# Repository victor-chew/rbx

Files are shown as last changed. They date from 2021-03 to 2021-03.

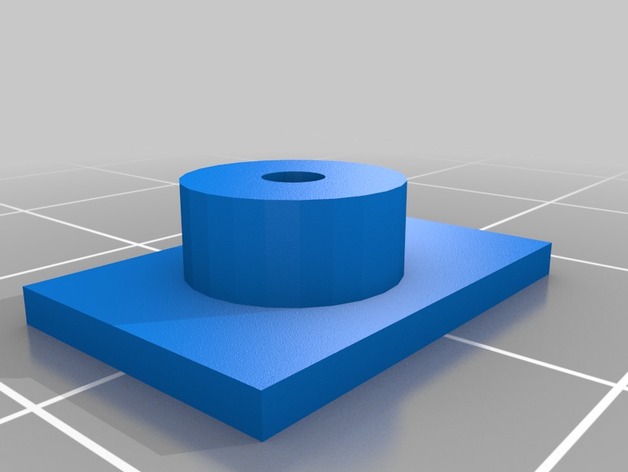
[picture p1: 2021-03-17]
freecad/servo/Printed_SG90_Servo_Connector/images/6eeb7df884c5a71ec6c0490531ae86ac_preview_featured.jpg

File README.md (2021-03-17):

# RBX

### What is RBX?

[RBX](https://rbx.randseq.org/) (*Robotics Brick Extension*) is a robotics kit designed for young tinkerers. It consists of a set of Lego-compatible "bricks" made with common  [Arduino](https://www.arduino.cc/)  components, such as LED, pushbutton, servo, motor etc. The brick housing are printed using a 3D printer. The RBX bricks are hooked up to a microcontroller via standardized "ports". Programming is done via a variant of [Javascript](https://duktape.org) on a browser-based IDE.

rbx mcu assembled Microcontroller (https://rbx.randseq.org/images/rbx/rbx-mcu-assembled.jpg) rbx battery aa Battery (4 x AA) (https://rbx.randseq.org/images/rbx/bricks/rbx-battery-aa.jpg) rbx battery 18650 Battery (18650) (https://rbx.randseq.org/images/rbx/bricks/rbx-battery-18650.jpg) rbx motor power Motor Power) (https://rbx.randseq.org/images/rbx/bricks/rbx-motor-power.jpg) rbx led LED (https://rbx.randseq.org/images/rbx/bricks/rbx-led.jpg) rbx pushbutton Pushbutton (https://rbx.randseq.org/images/rbx/bricks/rbx-pushbutton.jpg) rbx buzzer Buzzer (https://rbx.randseq.org/images/rbx/bricks/rbx-buzzer.jpg) rbx photoresistor Photoresistor (https://rbx.randseq.org/images/rbx/bricks/rbx-photoresistor.jpg) rbx oled OLED Display (https://rbx.randseq.org/images/rbx/bricks/rbx-oled.jpg) rbx rotary switch Rotary Switch (https://rbx.randseq.org/images/rbx/bricks/rbx-rotary-switch.jpg) rbx servo Servo (https://rbx.randseq.org/images/rbx/bricks/rbx-servo.jpg) rbx motor Motor (https://rbx.randseq.org/images/rbx/bricks/rbx-motor.jpg) rbx sonar Sonar (https://rbx.randseq.org/images/rbx/bricks/rbx-sonar.jpg) rbx color sensor Color Sensor (https://rbx.randseq.org/images/rbx/bricks/rbx-color-sensor.jpg)

### Target audience

The target audience is 8-12 year old children who need something between the simplicity of block-based programming environment such as Lego Mindstorm, and a full-blown IDE such as  [Arduino](https://www.arduino.cc/)  or  [PlatformIO](https://platformio.org/). Not only is Javascript the de-facto scripting language, it also eliminates the long compile-build-run cycle, which is more suited for experimentation with impatient young minds.

### Making hardware accessible

One of the first obstacles for a young student trying to break into microcontroller programming is hooking up the desired circuitry on a breadboard. Anything beyond the the introductory "Hello World" LED example requires a ton of wiring, which is quite a lot to ask for a young child. When servos or motors are involved, a separate power rail is required, which makes things even more complicated.

RBX uses various JST connectors to connect to the microcontroller. These are called "ports", which maps to the microcontroller pins. The ports come in 2, 3 and 4-pin variety, and each port has a unique identifier, Other connectors are used for providing power to motors or servos. In this way, hooking up stuff becomes a plug-and-play affair. Since the connectors need to be matching and oriented correctly, this makes it less likely for modules to be hooked up the wrong way.

### Microntroller

For the microcontroller, the ESP32 is chosen. It is incredibly powerful, and comes with built-in WIFI and bluetooth. The development board is also very affordable, available for only a few dollars online. It has a 2-core processor, and has enough RAM and flash storage to run a Javascript interpreter. It also has many pins available, which lets the microcontroller connect to many components simultaneously.

esp32 wroom 32d (https://rbx.randseq.org/images/rbx/esp32-wroom-32d.jpg)

### Programming made easy

For the JavaScript interpreter,  [Duktape](https://duktape.org/)  was ported to the ESP32.  [Duktape](https://duktape.org/)  has very low resource and memory requirement, which makes it particularly suited for a microcontroller.

A browser-based IDE is served directly from the microcontroller, using  [Ace](https://ace.c9.io/)  as the code editor. Once the microcontroller is powered on, the user is able to connect via a web browser and start running JavaScript code immediately. Code can be saved to the flash storage on the ESP32 and retrieved later.

rbx startup 06 (https://rbx.randseq.org/images/rbx/rbx-startup-06.png)

### Conclusion

In summary, RBX is relatively cheap to make, yet it is far more versatile than most of the pre-built electronic/robotic kits on the market. A young maker can get up to speed with the kit very quickly. As more experience is accumulated, he/she can delve into each of the "bricks" to see what makes them tick, or even make them from scratch.

On the software side, although we start with JavaScript, it is quite easy to switch to  [Arduino](https://www.arduino.cc/)  for more complex projects. At the root of RBX is an  [Arduino](https://www.arduino.cc/)  library, which is pretty straightforward to engage with directly for a more experienced  [Arduino](https://www.arduino.cc/)  programmer.

### Resources

 - [RBX website](https://rbx.randseq.org/)
 - [Sample projects](https://rbx.randseq.org/index.php/blinking-led)

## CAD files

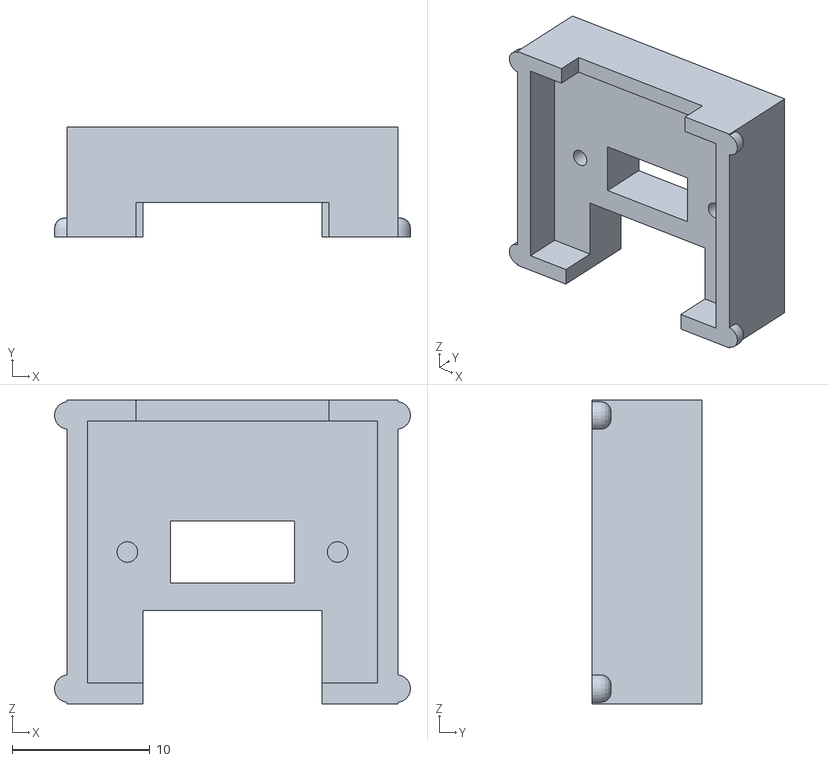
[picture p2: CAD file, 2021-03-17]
freecad/battery-18650/switch.stl
25.8 x 8.00 x 22.0

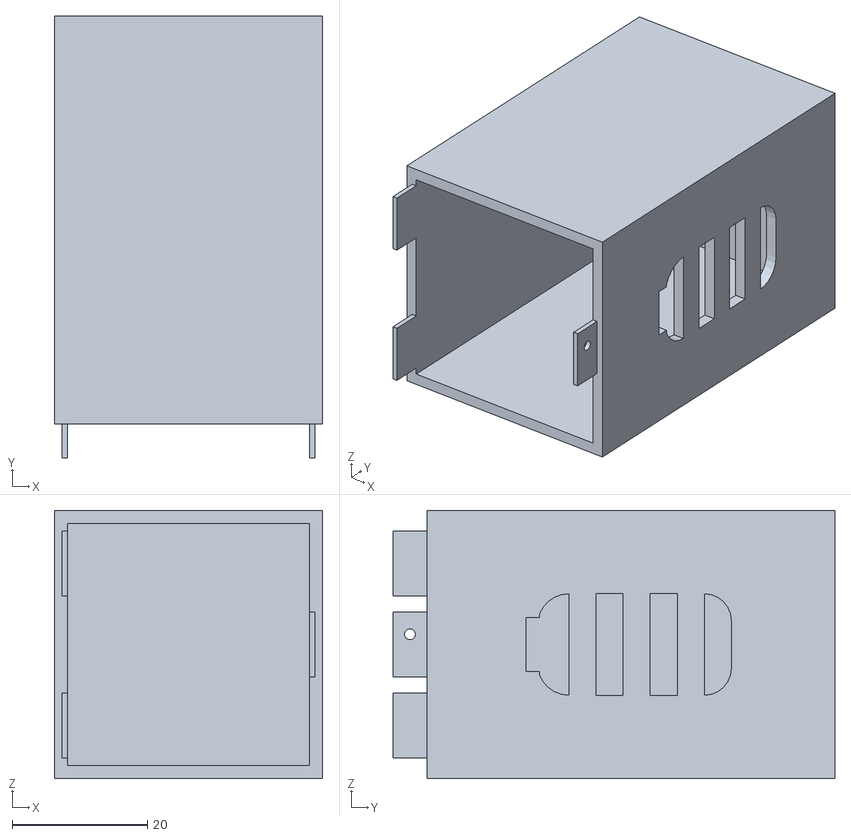
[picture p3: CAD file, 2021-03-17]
freecad/battery-AA/bottom.stl
39.6 x 65.3 x 39.6

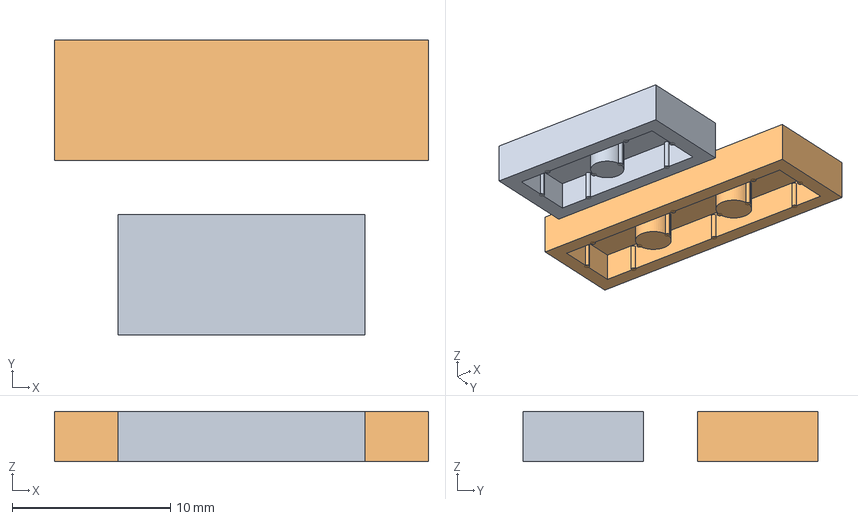
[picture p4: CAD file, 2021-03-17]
freecad/brickbase/brickbase.FCStd
23.6 x 18.6 x 3.16 mm
2x1-brickbase
3x1-brickbase

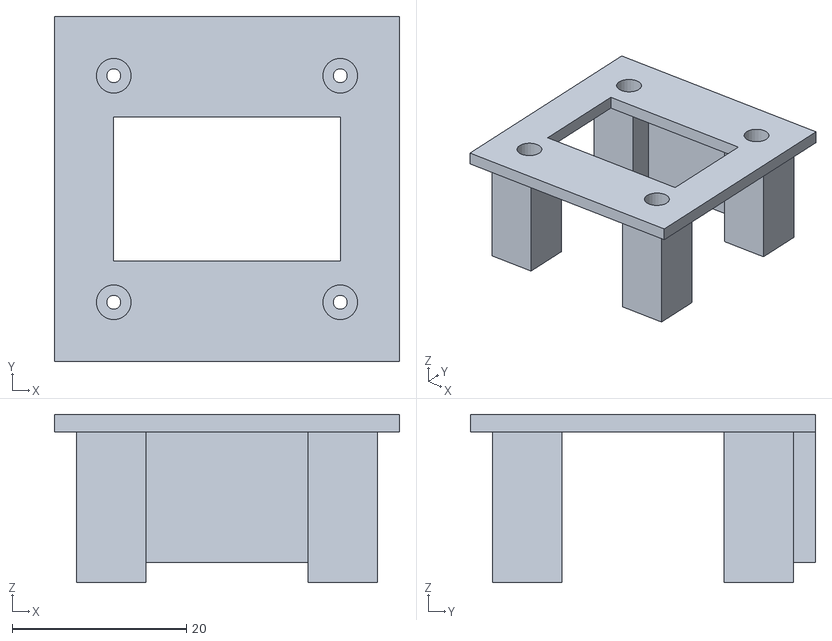
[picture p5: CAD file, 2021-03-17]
freecad/color-sensor/top.stl
39.6 x 39.6 x 19.3

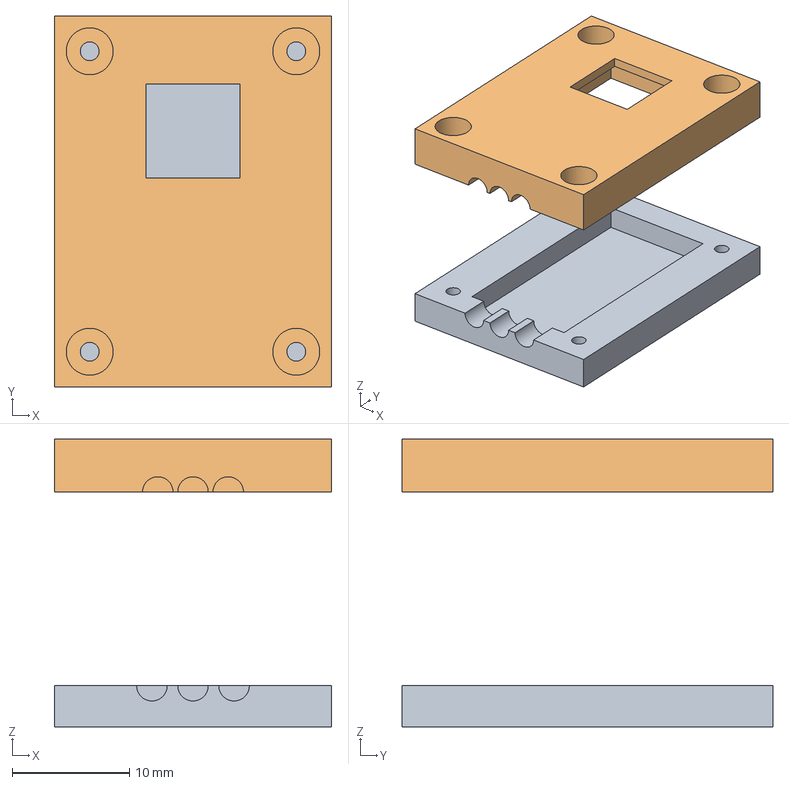
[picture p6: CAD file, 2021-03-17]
freecad/led/led.FCStd
23.6 x 31.6 x 24.5 mm
bottom
top

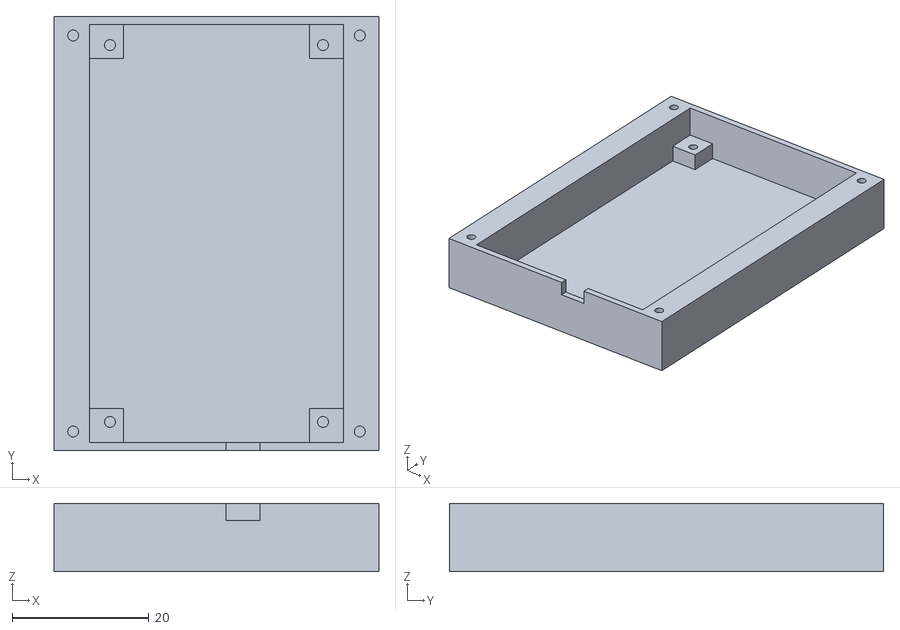
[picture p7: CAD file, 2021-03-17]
freecad/microcontroller/bottom.stl
47.6 x 63.6 x 10.0

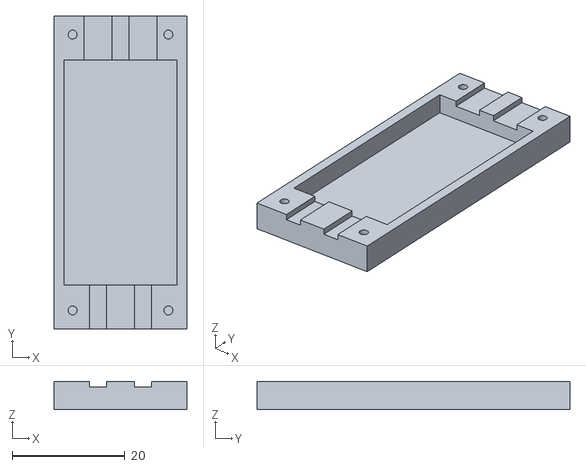
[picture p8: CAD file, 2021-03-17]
freecad/motor-power/bottom.stl
23.6 x 55.6 x 5.00

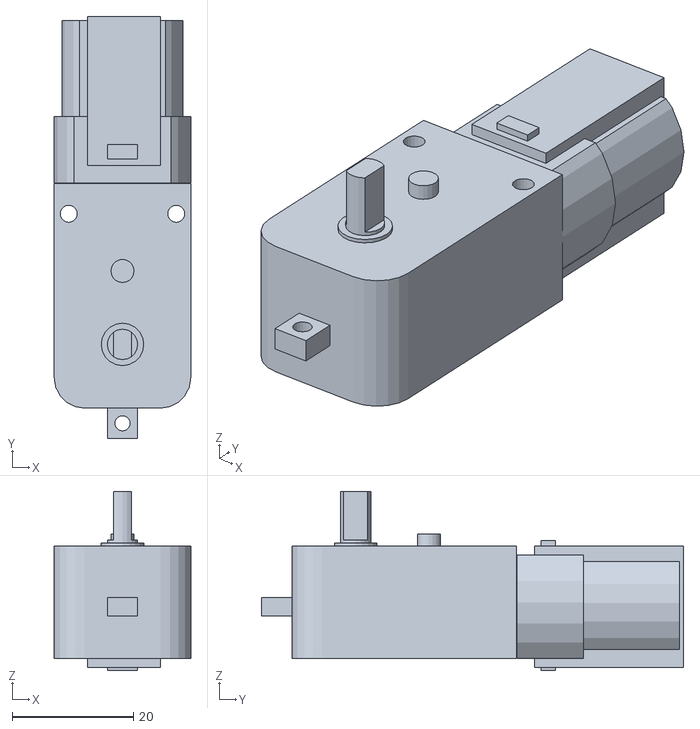
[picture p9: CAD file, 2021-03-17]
freecad/motor/5v_geared_motor_yellow.stl
22.5 x 69.5 x 29.5

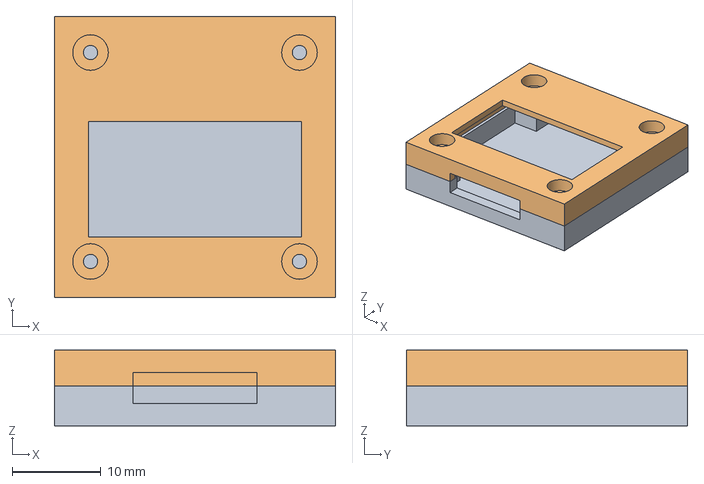
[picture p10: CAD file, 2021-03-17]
freecad/oled-display/oled-display.FCStd
31.6 x 31.6 x 8.50 mm
bottom
top

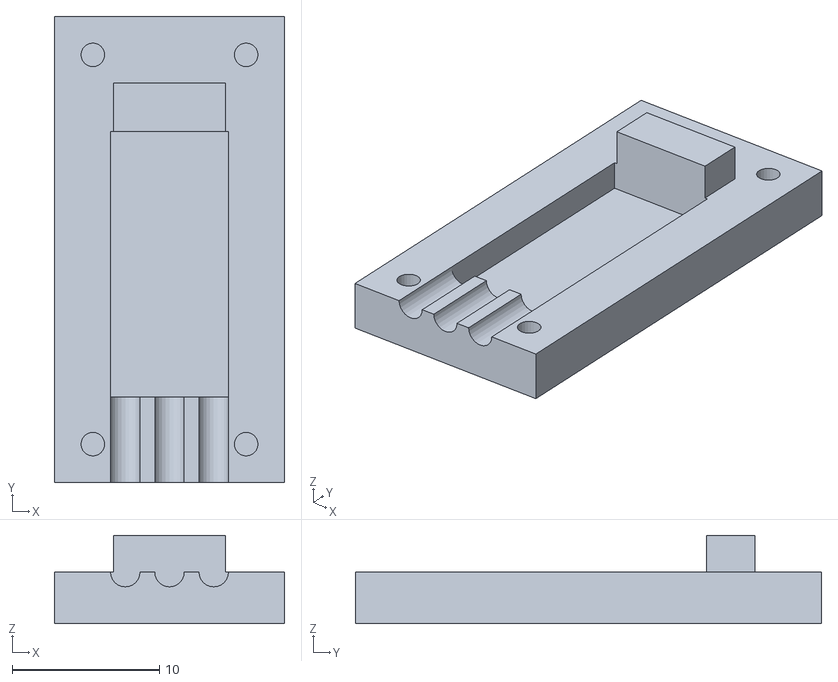
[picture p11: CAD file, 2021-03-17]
freecad/photoresistor/bottom.stl
15.6 x 31.6 x 6.00

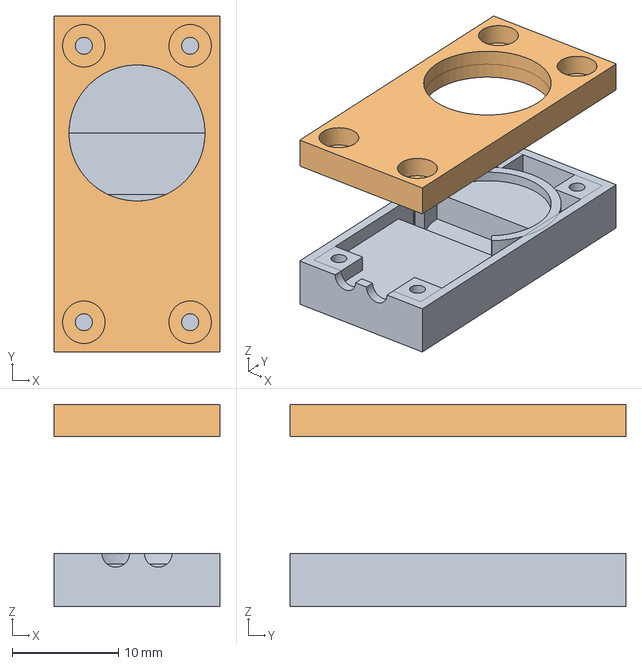
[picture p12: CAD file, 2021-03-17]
freecad/piezo-buzzer/piezo-buzzer.FCStd
15.6 x 31.6 x 19.0 mm
bottom
top

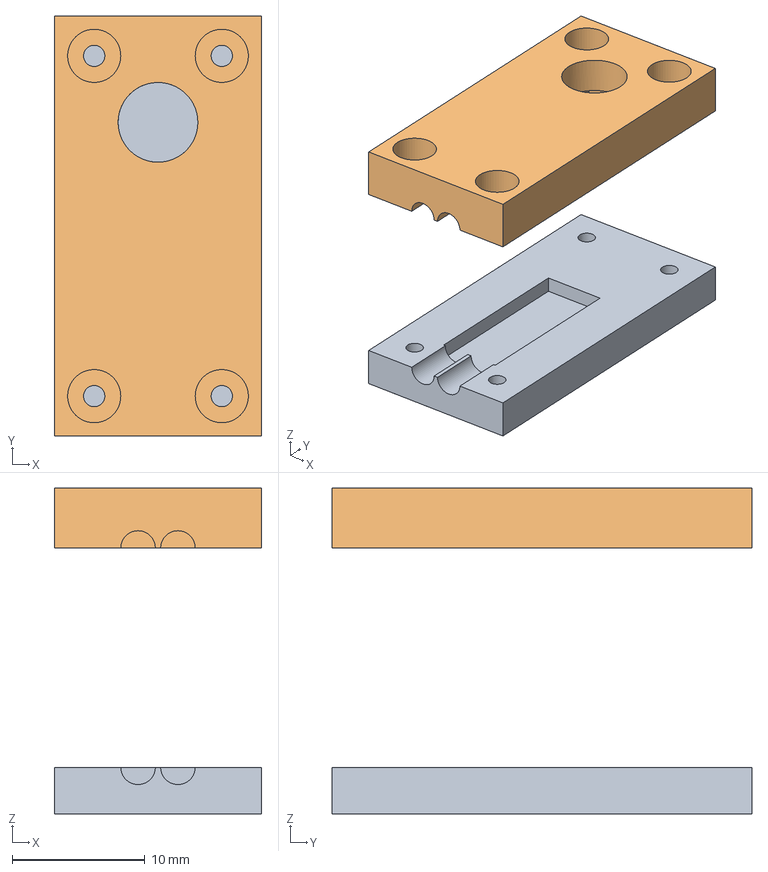
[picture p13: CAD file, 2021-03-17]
freecad/pushbutton/pushbutton.FCStd
15.6 x 31.6 x 24.5 mm
bottom
top

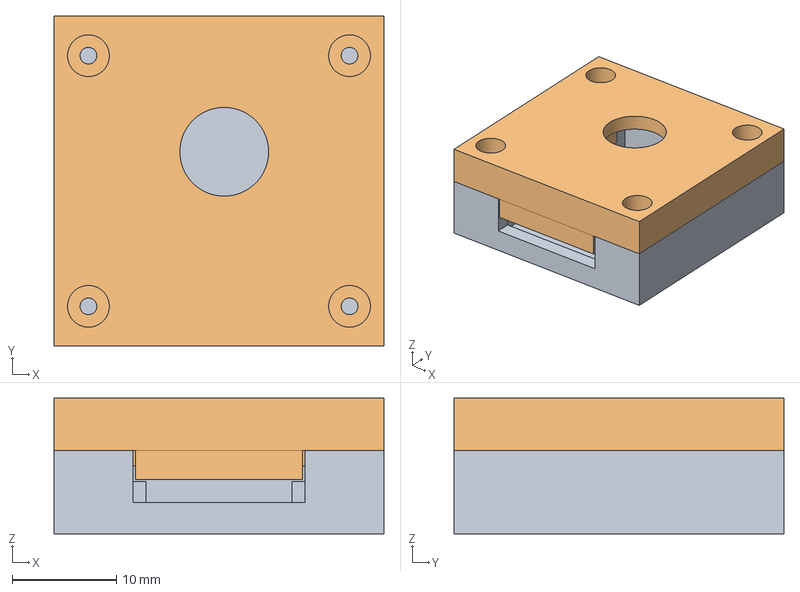
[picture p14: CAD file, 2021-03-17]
freecad/rotary-switch/rotary-switch.FCStd
31.6 x 31.6 x 13.0 mm
bottom
top

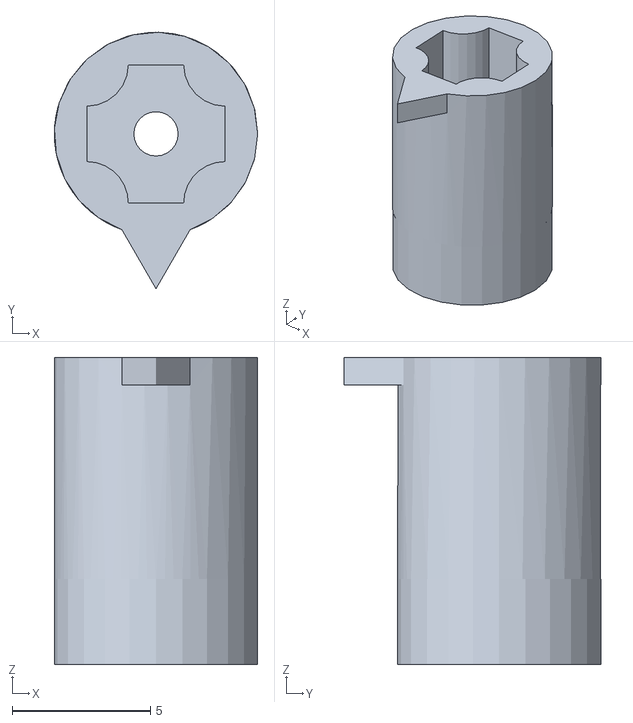
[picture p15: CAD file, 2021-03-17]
freecad/servo/axle-adapter.stl
7.35 x 9.27 x 11.1

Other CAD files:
freecad/servo/Printed_SG90_Servo_Connector/files/9g_conn_top.stl
freecad/sonar/back.stl
freecad/battery-18650/switch-cover.stl
freecad/battery-AA/battery-AA.FCStd
freecad/battery-18650/battery-18650.FCStd
freecad/battery-18650/bottom.stl
freecad/battery-18650/holder.stl
freecad/battery-18650/top.stl
freecad/battery-AA/holder-mirror.stl
freecad/battery-AA/holder.stl
freecad/battery-AA/switch.stl
freecad/brickbase/2x1.3mf
freecad/brickbase/2x1.stl
freecad/brickbase/3x1.3mf
freecad/brickbase/3x1.stl
freecad/color-sensor/bottom.stl
freecad/color-sensor/color-sensor.FCStd
freecad/led/bottom.stl
freecad/led/top.stl
freecad/microcontroller/controller.FCStd
freecad/microcontroller/top.stl
freecad/motor-power/motor-power.FCStd
freecad/motor-power/top.stl
freecad/motor/axle-adapter.stl
freecad/motor/axle-long.stl
freecad/motor/axle-short.stl
freecad/motor/back.stl
freecad/motor/cover.stl
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

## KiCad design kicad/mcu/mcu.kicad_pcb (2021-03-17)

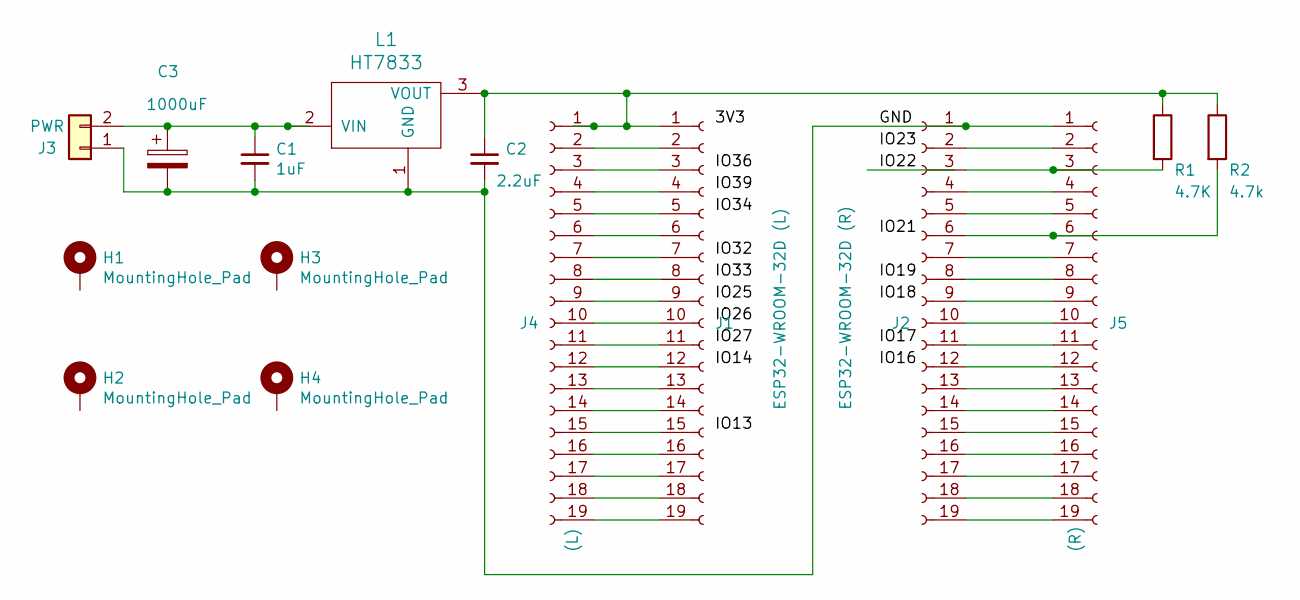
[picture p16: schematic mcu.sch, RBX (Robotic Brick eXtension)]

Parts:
C1: 1uF; C_Disc_D3.0mm_W1.6mm_P2.50mm
C2: 2.2uF; C_Disc_D3.0mm_W1.6mm_P2.50mm
C3: 1000uF; CP_Radial_D4.0mm_P2.00mm
H1, H2, H3, H4: MountingHole_Pad; MountingHole_2.5mm_Pad
J1: ESP32-WROOM-32D (L); PinSocket_1x19_P2.54mm_Vertical
J2: ESP32-WROOM-32D (R); PinSocket_1x19_P2.54mm_Vertical
J3: PWR; PinSocket_1x02_P2.54mm_Vertical
J4: (L); PinSocket_1x19_P2.54mm_Vertical
J5: (R); PinSocket_1x19_P2.54mm_Vertical
L1: HT7833; TO-92
R1: 4.7K; R_Axial_DIN0204_L3.6mm_D1.6mm_P5.08mm_Horizontal
R2: 4.7k; R_Axial_DIN0204_L3.6mm_D1.6mm_P5.08mm_Horizontal

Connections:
/GND: C1.2, C2.2, C3.2, J2.1, J3.1, J5.1, L1.1 (GND)
unnamed: C1.1, C3.1, J3.2, L1.2 (VIN)
unnamed: C2.1, J1.1, J4.1, L1.3 (VOUT), R1.1, R2.1
unnamed: J1.2, J4.2
unnamed: J1.3, J4.3
unnamed: J1.4, J4.4
unnamed: J1.5, J4.5
unnamed: J1.6, J4.6
unnamed: J1.7, J4.7
unnamed: J1.8, J4.8
unnamed: J1.9, J4.9
unnamed: J1.10, J4.10
unnamed: J1.11, J4.11
unnamed: J1.12, J4.12
unnamed: J1.13, J4.13
unnamed: J1.14, J4.14
unnamed: J1.15, J4.15
unnamed: J1.16, J4.16
unnamed: J1.17, J4.17
unnamed: J1.18, J4.18
unnamed: J1.19, J4.19
unnamed: J2.2, J5.2
unnamed: J2.3, J5.3, R1.2
unnamed: J2.4, J5.4
unnamed: J2.5, J5.5
unnamed: J2.6, J5.6, R2.2
unnamed: J2.7, J5.7
unnamed: J2.8, J5.8
unnamed: J2.9, J5.9
unnamed: J2.10, J5.10
unnamed: J2.11, J5.11
unnamed: J2.12, J5.12
unnamed: J2.13, J5.13
unnamed: J2.14, J5.14
unnamed: J2.15, J5.15
unnamed: J2.16, J5.16
unnamed: J2.17, J5.17
unnamed: J2.18, J5.18
unnamed: J2.19, J5.19

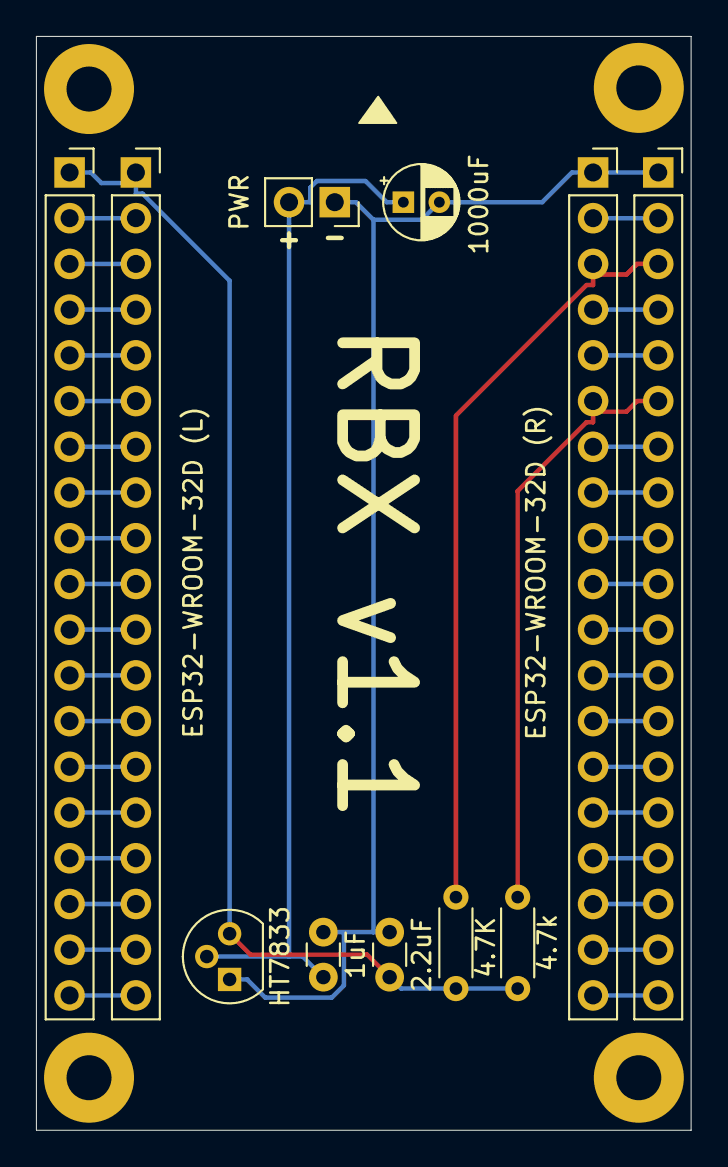
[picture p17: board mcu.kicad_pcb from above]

Board: 2 copper layers, 36.4 x 60.8 mm, 15 parts (0 on the bottom side), 39 nets.

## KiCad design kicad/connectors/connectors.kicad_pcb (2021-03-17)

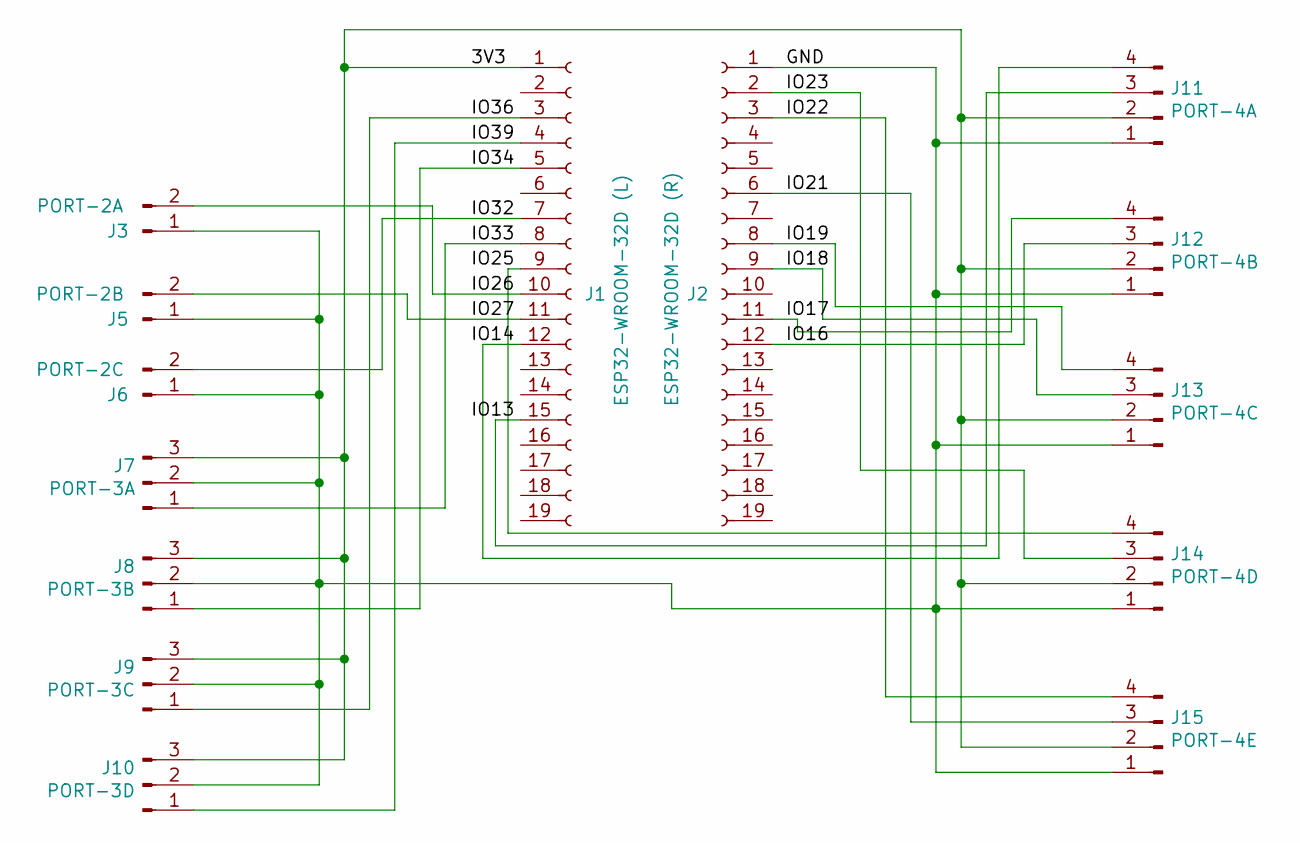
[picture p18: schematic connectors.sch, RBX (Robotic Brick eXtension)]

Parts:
J1: ESP32-WROOM-32D (L); PinSocket_1x19_P2.54mm_Vertical
J2: ESP32-WROOM-32D (R); PinSocket_1x19_P2.54mm_Vertical
J3: PORT-2A; JST_XH_B2B-XH-A_1x02_P2.50mm_Vertical
J5: PORT-2B; JST_XH_B2B-XH-A_1x02_P2.50mm_Vertical
J6: PORT-2C; JST_XH_B2B-XH-A_1x02_P2.50mm_Vertical
J7: PORT-3A; JST_XH_B3B-XH-A_1x03_P2.50mm_Vertical
J8: PORT-3B; JST_XH_B3B-XH-A_1x03_P2.50mm_Vertical
J9: PORT-3C; JST_XH_B3B-XH-A_1x03_P2.50mm_Vertical
J10: PORT-3D; JST_XH_B3B-XH-A_1x03_P2.50mm_Vertical
J11: PORT-4A; JST_XH_B4B-XH-A_1x04_P2.50mm_Vertical
J12: PORT-4B; JST_XH_B4B-XH-A_1x04_P2.50mm_Vertical
J13: PORT-4C; JST_XH_B4B-XH-A_1x04_P2.50mm_Vertical
J14: PORT-4D; JST_XH_B4B-XH-A_1x04_P2.50mm_Vertical
J15: PORT-4E; JST_XH_B4B-XH-A_1x04_P2.50mm_Vertical

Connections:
/3V3: J1.1, J7.3, J8.3, J9.3, J10.3, J11.2, J12.2, J13.2, J14.2, J15.2
/GND: J2.1, J3.1, J5.1, J6.1, J7.2, J8.2, J9.2, J10.2, J11.1, J12.1, J13.1, J14.1, J15.1
/IO16: J2.12, J12.3
/IO17: J2.11, J12.4
/IO18: J2.9, J13.3
/IO19: J2.8, J13.4
/IO21: J2.6, J15.3
/IO22: J2.3, J15.4
/IO23: J2.2, J14.3
/IO26: J1.10, J3.2
/IO27: J1.11, J5.2
/IO32: J1.7, J6.2
/IO33: J1.8, J7.1
/IO34: J1.5, J8.1
/IO36: J1.3, J9.1
/IO39: J1.4, J10.1
unnamed: J1.9, J14.4
unnamed: J1.12, J11.4
unnamed: J1.15, J11.3

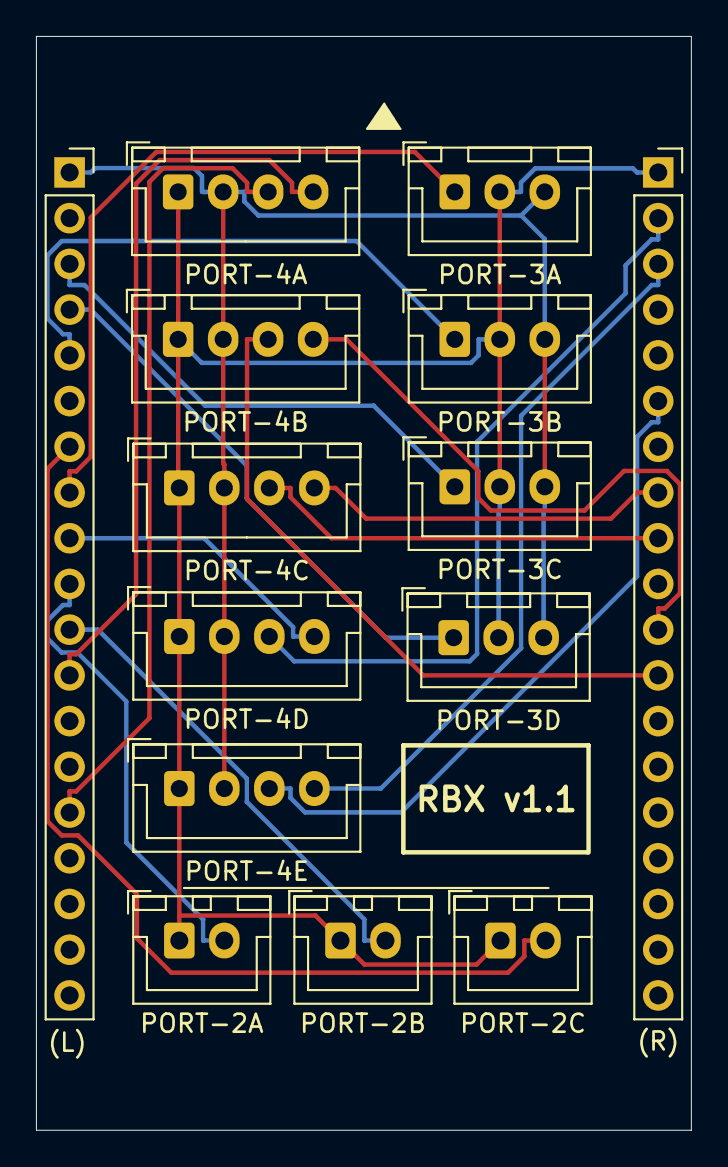
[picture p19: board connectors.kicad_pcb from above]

Board: 2 copper layers, 36.4 x 60.8 mm, 14 parts (0 on the bottom side), 19 nets.

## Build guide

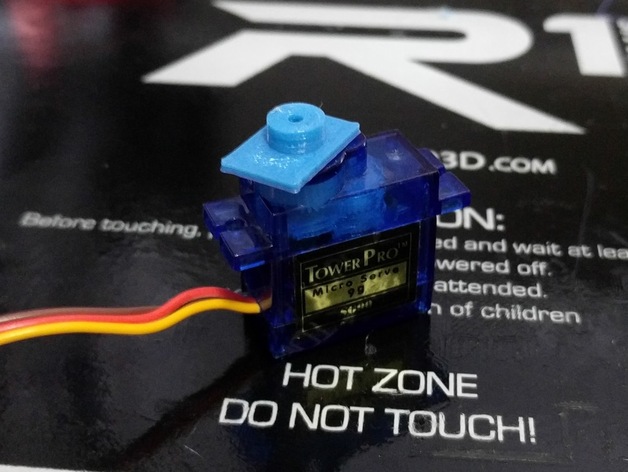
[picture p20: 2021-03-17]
freecad/servo/Printed_SG90_Servo_Connector/images/e1a54dfbaee857ab177775c9e213d912_preview_featured.jpg

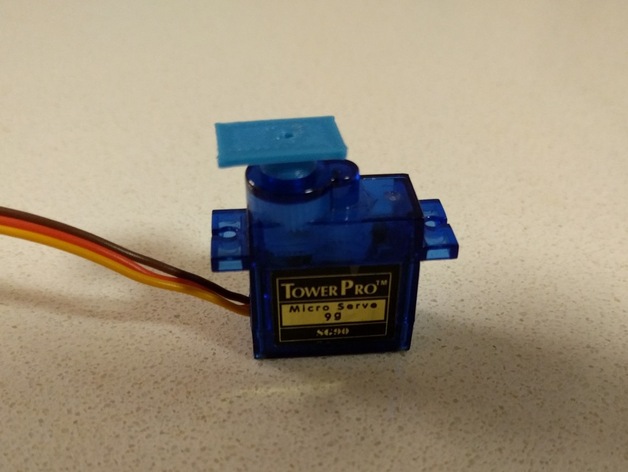
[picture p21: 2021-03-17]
freecad/servo/Printed_SG90_Servo_Connector/images/eb84d0ea47f26ba00e28bbcdb9098030_preview_featured.jpg

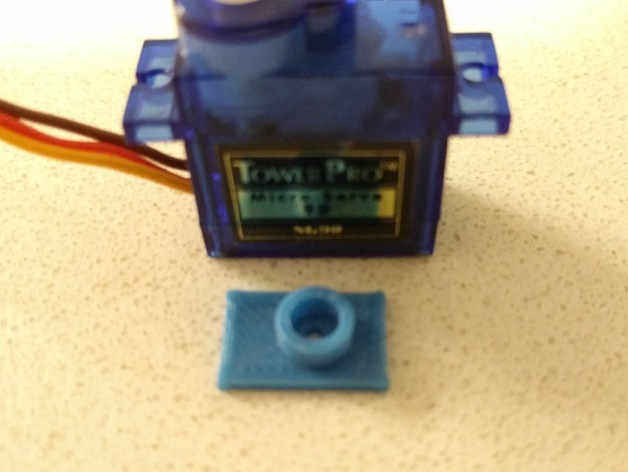
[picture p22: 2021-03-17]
freecad/servo/Printed_SG90_Servo_Connector/images/e64788267c30d9ad906c26ac2d321aa9_preview_featured.jpg

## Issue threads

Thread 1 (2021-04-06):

Shut up and take my money

JamesNewton, 2021-04-06:
Where can I purchase hardware kits? E.g. PCBs with or without components on them, or full modules?

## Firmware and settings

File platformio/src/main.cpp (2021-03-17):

/*
 * main.cpp
 *
 * Copyright 2020 Victor Chew
 *
 * Licensed under the Apache License, Version 2.0 (the "License");
 * you may not use this file except in compliance with the License.
 * You may obtain a copy of the License at
 *
 *     http://www.apache.org/licenses/LICENSE-2.0
 *
 * Unless required by applicable law or agreed to in writing, software
 * distributed under the License is distributed on an "AS IS" BASIS,
 * WITHOUT WARRANTIES OR CONDITIONS OF ANY KIND, either express or implied.
 * See the License for the specific language governing permissions and
 * limitations under the License.
 */

#include <stdarg.h>
#include <Arduino.h>
#include <Wire.h>
#include <WiFi.h>
#include <SPIFFS.h>
#include <rbx.h>
#include "javascript.h"
#include "webserver.h"

OledDisplay screen;

void showInfo(OledDisplay& screen, const char* title, const char* msg) {
  screen.clear();
  int sw = screen.stringWidth(msg);
  int sh = screen.stringHeight(msg);
  int sx = (screen.width() - sw) / 2;
  int sy = ((screen.height() - (sh*3)) / 2) + sh;
  screen.drawString(sx, sy, title);
  screen.drawString(sx, sy + (sh*2), msg);
}

void setup() {
  Serial.begin(115200);
  if (!SPIFFS.begin(true)) Serial.println("SPIFFS cannot be mounted.");

  Wire.begin();

  // Display SSID on OLED display
  uint32_t chipId = 0;
  for(int i=0; i<17; i=i+8) chipId |= ((ESP.getEfuseMac() >> (40 - i)) & 0xff) << i;
  String ssid = String("RBX-") + String(chipId);
  Serial.print("SSID: "); Serial.println(ssid);  
  showInfo(screen, "Setup:", ssid.c_str());

  // Connect to router, then initialize web server and Javascript runtime
  OTA_Init(ssid.c_str());
  initWebServer();
  initJavascript();

  // Display IP address on screen
  IPAddress ipaddr = WiFi.localIP(); 
  showInfo(screen, "Connected:", ipaddr.toString().c_str());

  // Start autorun script (if any)
  autorunJavascript();
}

void loop() {
  vTaskDelete(NULL);
}

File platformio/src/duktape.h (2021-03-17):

/*
 *  Duktape public API for Duktape 2.5.0.
 *
 *  See the API reference for documentation on call semantics.  The exposed,
 *  supported API is between the "BEGIN PUBLIC API" and "END PUBLIC API"
 *  comments.  Other parts of the header are Duktape internal and related to
 *  e.g. platform/compiler/feature detection.
 *
 *  Git commit external (external).
 *  Git branch external.
 *
 *  See Duktape AUTHORS.rst and LICENSE.txt for copyright and
 *  licensing information.
 */

/* LICENSE.txt */
/*
 *  ===============
 *  Duktape license
 *  ===============
 *  
 *  (http://opensource.org/licenses/MIT)
 *  
 *  Copyright (c) 2013-2019 by Duktape authors (see AUTHORS.rst)
 *  
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
 *  THE SOFTWARE IS PROVIDED "AS IS", WITHOUT WARRANTY OF ANY KIND, EXPRESS OR
 *  IMPLIED, INCLUDING BUT NOT LIMITED TO THE WARRANTIES OF MERCHANTABILITY,
 *  FITNESS FOR A PARTICULAR PURPOSE AND NONINFRINGEMENT. IN NO EVENT SHALL THE
 *  AUTHORS OR COPYRIGHT HOLDERS BE LIABLE FOR ANY CLAIM, DAMAGES OR OTHER
 *  LIABILITY, WHETHER IN AN ACTION OF CONTRACT, TORT OR OTHERWISE, ARISING FROM,
 *  OUT OF OR IN CONNECTION WITH THE SOFTWARE OR THE USE OR OTHER DEALINGS IN
 *  THE SOFTWARE.
 */

/* AUTHORS.rst */
/*
 *  ===============
 *  Duktape authors
 *  ===============
 *  
 *  Copyright
 *  =========
 *  
 *  Duktape copyrights are held by its authors.  Each author has a copyright
 *  to their contribution, and agrees to irrevocably license the contribution
 *  under the Duktape ``LICENSE.txt``.
 *  
 *  Authors
 *  =======
 *  
 *  Please include an e-mail address, a link to your GitHub profile, or something
 *  similar to allow your contribution to be identified accurately.
 *  
 *  The following people have contributed code, website contents, or Wiki contents,
 *  and agreed to irrevocably license their contributions under the Duktape
 *  ``LICENSE.txt`` (in order of appearance):
 *  
 *  * Sami Vaarala <sami.vaarala@iki.fi>
 *  * Niki Dobrev
 *  * Andreas \u00d6man <andreas@lonelycoder.com>
 *  * L\u00e1szl\u00f3 Lang\u00f3 <llango.u-szeged@partner.samsung.com>
 *  * Legimet <legimet.calc@gmail.com>
 *  * Karl Skomski <karl@skomski.com>
 *  * Bruce Pascoe <fatcerberus1@gmail.com>
 *  * Ren\u00e9 Hollander <rene@rene8888.at>
 *  * Julien Hamaide (https://github.com/crazyjul)
 *  * Sebastian G\u00f6tte (https://github.com/jaseg)
 *  * Tomasz Magulski (https://github.com/magul)
 *  * \D. Bohdan (https://github.com/dbohdan)
 *  * Ond\u0159ej Jirman (https://github.com/megous)
 *  * Sa\u00fal Ibarra Corretg\u00e9 <saghul@gmail.com>
 *  * Jeremy HU <huxingyi@msn.com>
 *  * Ole Andr\u00e9 Vadla Ravn\u00e5s (https://github.com/oleavr)
 *  * Harold Brenes (https://github.com/harold-b)
 *  * Oliver Crow (https://github.com/ocrow)
 *  * Jakub Ch\u0142api\u0144ski (https://github.com/jchlapinski)
 *  * Brett Vickers (https://github.com/beevik)
 *  * Dominik Okwieka (https://github.com/okitec)
 *  * Remko Tron\u00e7on (https://el-tramo.be)
 *  * Romero Malaquias (rbsm@ic.ufal.br)
 *  * Michael Drake <michael.drake@codethink.co.uk>
 *  * Steven Don (https://github.com/shdon)
 *  * Simon Stone (https://github.com/sstone1)
 *  * \J. McC. (https://github.com/jmhmccr)
 *  * Jakub Nowakowski (https://github.com/jimvonmoon)
 *  * Tommy Nguyen (https://github.com/tn0502)
 *  * Fabrice Fontaine (https://github.com/ffontaine)
 *  * Christopher Hiller (https://github.com/boneskull)
 *  * Gonzalo Diethelm (https://github.com/gonzus)
 *  * Michal Kasperek (https://github.com/michalkas)
 *  * Andrew Janke (https://github.com/apjanke)
 *  * Steve Fan (https://github.com/stevefan1999)
 *  * Edward Betts (https://github.com/edwardbetts)
 *  * Ozhan Duz (https://github.com/webfolderio)
 *  * Akos Kiss (https://github.com/akosthekiss)
 *  * TheBrokenRail (https://github.com/TheBrokenRail)
 *  * Jesse Doyle (https://github.com/jessedoyle)
 *  * Gero Kuehn (https://github.com/dc6jgk)
 *  * James Swift (https://github.com/phraemer)
 *  * Luis de Bethencourt (https://github.com/luisbg)
 *  * Ian Whyman (https://github.com/v00d00)
 *  * Rick Sayre (https://github.com/whorfin)
 *  
 *  Other contributions
 *  ===================
 *  
 *  The following people have contributed something other than code (e.g. reported
 *  bugs, provided ideas, etc; roughly in order of appearance):
 *  
 *  * Greg Burns
 *  * Anthony Rabine
 *  * Carlos Costa
 *  * Aur\u00e9lien Bouilland
 *  * Preet Desai (Pris Matic)
 *  * judofyr (http://www.reddit.com/user/judofyr)
 *  * Jason Woofenden
 *  * Micha\u0142 Przyby\u015b
 *  * Anthony Howe
 *  * Conrad Pankoff
 *  * Jim Schimpf
 *  * Rajaran Gaunker (https://github.com/zimbabao)
 *  * Andreas \u00d6man
 *  * Doug Sanden
 *  * Josh Engebretson (https://github.com/JoshEngebretson)
 *  * Remo Eichenberger (https://github.com/remoe)
 *  * Mamod Mehyar (https://github.com/mamod)
 *  * David Demelier (https://github.com/markand)
 *  * Tim Caswell (https://github.com/creationix)
 *  * Mitchell Blank Jr (https://github.com/mitchblank)
 *  * https://github.com/yushli
 *  * Seo Sanghyeon (https://github.com/sanxiyn)
 *  * Han ChoongWoo (https://github.com/tunz)
 *  * Joshua Peek (https://github.com/josh)
 *  * Bruce E. Pascoe (https://github.com/fatcerberus)
 *  * https://github.com/Kelledin
 *  * https://github.com/sstruchtrup
 *  * Michael Drake (https://github.com/tlsa)
 *  * https://github.com/chris-y
 *  * Laurent Zubiaur (https://github.com/lzubiaur)
 *  * Neil Kolban (https://github.com/nkolban)
 *  * Wilhelm Wanecek (https://github.com/wanecek)
 *  * Andrew Janke (https://github.com/apjanke)
 *  * Unamer (https://github.com/unamer)
 *  * Karl Dahlke (eklhad@gmail.com)
 *  
 *  If you are accidentally missing from this list, send me an e-mail
 *  (``sami.vaarala@iki.fi``) and I'll fix the omission.
 */

#pragma GCC diagnostic ignored "-Wunused-function"

#if !defined(DUKTAPE_H_INCLUDED)
#define DUKTAPE_H_INCLUDED

#define DUK_SINGLE_FILE

/*
 *  BEGIN PUBLIC API
 */

/*
 *  Version and Git commit identification
 */

/* Duktape version, (major * 10000) + (minor * 100) + patch.  Allows C code
 * to #if (DUK_VERSION >= NNN) against Duktape API version.  The same value
 * is also available to ECMAScript code in Duktape.version.  Unofficial
 * development snapshots have 99 for patch level (e.g. 0.10.99 would be a
 * development version after 0.10.0 but before the next official release).
 */
#define DUK_VERSION                       20500L

/* Git commit, describe, and branch for Duktape build.  Useful for
 * non-official snapshot builds so that application code can easily log
 * which Duktape snapshot was used.  Not available in the ECMAScript
 * environment.
 */
#define DUK_GIT_COMMIT                    "external"
#define DUK_GIT_DESCRIBE                  "external"
#define DUK_GIT_BRANCH                    "external"
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
